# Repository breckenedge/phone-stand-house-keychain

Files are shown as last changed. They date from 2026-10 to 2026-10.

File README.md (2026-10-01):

# House Keychain Phone Stand

A 1" × 1" × 0.75" (25.4 × 25.4 × 19 mm) house keychain. The front half swings
down on a print-in-place hinge and turns into a phone stand. The lid's roof
edge overlaps the back half's roof like a shingle and snaps shut: two small ridges under
its edge click into pockets in the back half's roof.

## Files

- `house_keychain.scad`: the model. Set `part` to `closed`, `open`, `print`, `body`, or `lid`.
- `house_keychain_print.stl`: the whole keychain as one print, with the lid folded open.

- `hotel_keychain.scad`: the hotel, a 1" × 2.5" × 0.75" version (see below). It includes the house model and only changes a few values.
- `hotel_keychain_print.stl`: the hotel as one print, with the lid folded open.

## Printing

- Print `house_keychain_print.stl` as exported: body upright and lid flat, joined only by the hinge.
- No supports needed.
- PETG (tougher and more heat-resistant than PLA, which matters for a keychain). 0.4 mm nozzle, 0.12 mm layers or finer.
- Use a textured plate or glue stick: PETG can bond too well to smooth PEI.
- In the slicer preview, check that the 0.35 mm hinge gaps show up as gaps and aren't filled in.
- After printing, work the hinge back and forth a few times to free it. Then fold the lid up until it clicks.

## Using it as a stand

Fold the lid down flat. Set the phone's bottom edge on the open lid, just in
front of the hinge. The phone leans back against the roof ridge at about 15°,
and the lid's roof edge acts as a lip that stops it sliding forward. Phones up
to about 12 mm thick, case included, fit between the hinge and the lip.

The stand is tiny, so **landscape is the stable orientation**. Portrait works
with lighter phones, but it can tip backward.

## The hotel

The hotel is 2.5" (63.5 mm) tall with the same footprint, hinge and roof snap.
Its whole front wall folds down into a 2.5" base. The phone's bottom edge sits
out on that base against a rib and leans back on the roof ridge at 20°. Because
the phone stands well forward of the hotel and is held 2.5" up, portrait is
stable too.

- `phone_lean`: the lean angle (20°). It sets how far out on the base the phone sits. 0 gives the house layout.
- `lip_h`: rib height (6 mm). The rib sits just past the front of a `phone_t` phone and folds away inside the closed hotel.
- `roof_h`: eave-to-peak height (9 mm).
- `floors`, `floor_h`: rows of windows and their spacing.

## Tuning

- `pip_clr`: hinge gap, 0.35 mm for PETG. Raise to 0.4 if the hinge prints fused. Lower it (0.3 suits PLA) if it's floppy.
- `open_stop`: the middle hinge knuckle has a square foot, which makes the house's bottom flat. Opened past flat, the
  foot runs head-on into the end of the body's floor, so the lid stops at about 99° (about 105° with the hinge's play
  taken up). It can't stop at exactly 90°: the foot has to print `clr` (0.3 mm) clear of the floor.
- `hinge_r`: knuckle radius, 3 mm. A bigger hinge gives a firmer stop, but it also raises the eave, which flattens the roof.
- `snap`: how firmly the lid clicks shut (how far the lid's ridges reach into the body's roof). 0.35 mm for PETG. Use 0.3 for PLA: it gives a good click in PLA but was too soft in PETG.
  The part that flexes is mostly the lid's thin roof edge. The ridges print as horizontal ribs on it, so
  their height comes from the XY accuracy of the printer, not from the layer height.
- `overlap`, `lip_t`, `fit`: how far the lid's roof edge laps over the body's roof,
  how thick that edge is, and the gap under it. `under_t` thickens the body roof
  under the overlap. `bump_dx` sets how far the ridges sit from the peak.
- `snap_ridge`: how long each ridge is along the roof slope (4 mm by default), for a firmer
  click in PETG. Set it to 0 for round bumps.
- `phone_t`: the thickest phone, case included, that the stand fits (12 mm by default). The eave
  height is calculated from it: thicker phones mean higher walls and a flatter roof. Anything over
  about 16 mm is rejected with an error. When run, the `open` view echoes the lean angle and where the lip is.
- `roof_split`: a higher value gives a more upright phone but a smaller lip.
- `keyring_d`: keyring hole size, 3 mm by default and up to about 5 mm. The hole runs sideways through the top of the
  chimney, so the ring loops over the chimney when closed and lies flat past the end of the lid
  when it's open. The chimney gets deeper and taller to fit bigger holes, and rises above the 1"
  peak from about 3 mm up. `chim_rim` sets the material around the hole and `chim_cap` the material above it.
- `chamfer`: bevel on all the outside edges (0.8 mm) so it doesn't snag in a pocket.
- `details`: door and windows. Off by default (house and hotel).

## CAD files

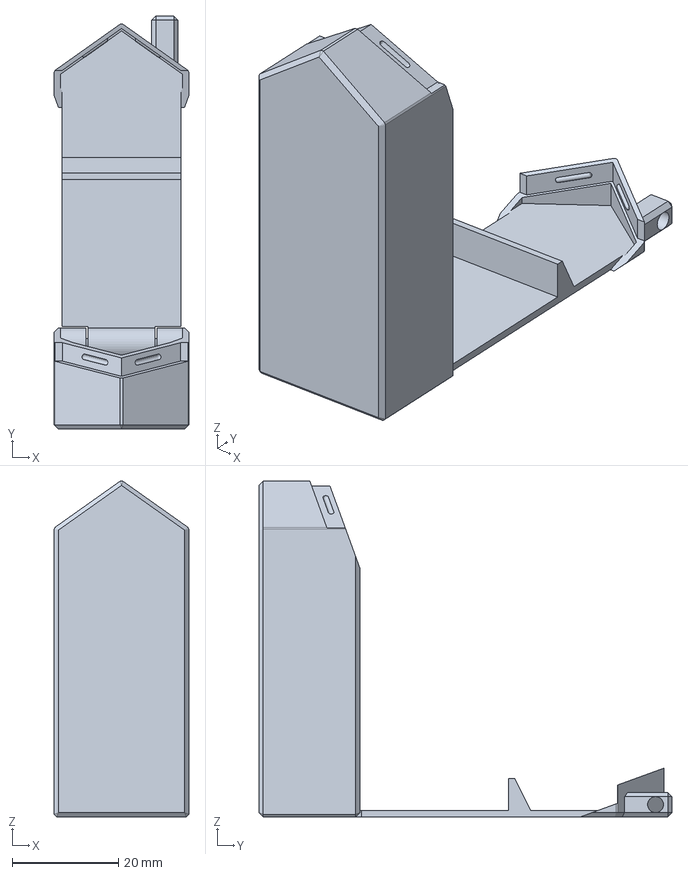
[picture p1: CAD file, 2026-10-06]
hotel_keychain_print.3mf
25.4 x 77.9 x 63.3 mm

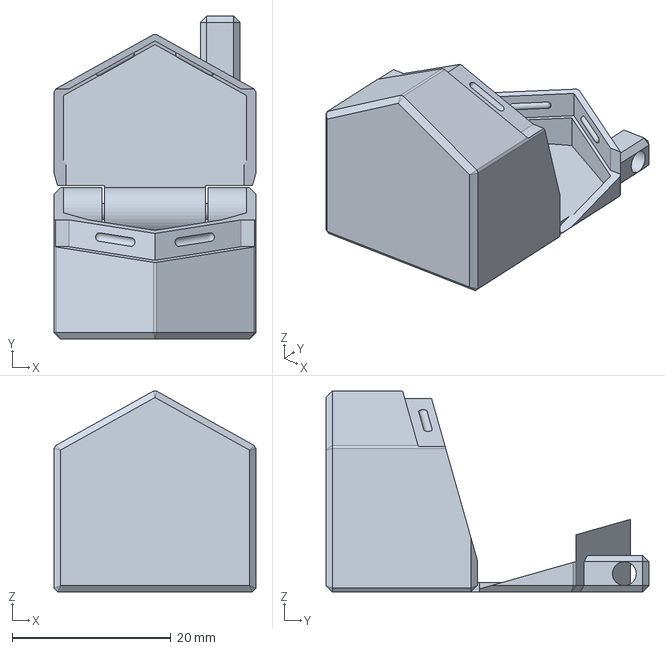
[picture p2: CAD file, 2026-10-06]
house_keychain_print.3mf
25.4 x 40.7 x 25.3 mm

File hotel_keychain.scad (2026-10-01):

// Hotel Keychain Phone Stand
// The house's tall sibling: 1" x 2.5" x 0.75". Same hinge and roof snap, but the
// whole front wall folds down into a 2.5" base. The phone's bottom edge sits out
// on that base against a rib and leans on the roof ridge, 2.5" up.
// Everything is modelled in house_keychain.scad; this file only sets the hotel's
// values (the ones here win over the house's defaults).

include <house_keychain.scad>

part = "open"; // [closed, open, print, body, lid]
H = 63.5;           // height to roof peak (2.5")
phone_lean = 20;    // degrees
floors = 4;         // window rows, if details is turned on

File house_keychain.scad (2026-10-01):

// House Keychain Phone Stand
// A 1" x 1" x 0.75" house. The front half folds down on a hinge and becomes a
// phone stand: the phone's bottom edge sits on the open lid just past the hinge,
// leans on the roof ridge, and the lid's roof edge is the lip in front.
// The body/lid seam is one slanted line along the phone's lean. On the roof, the
// lid's edge overlaps the body's roof like a shingle and snaps over two bumps.
//
// Coordinates: X = width, Y = depth (0 = back, D = front), Z = up.
// Print-in-place hinge: the lid's middle knuckle carries a pin that runs into
// blind holes in the body's end knuckles. Print the whole thing in one piece
// with the lid folded open (part = "print").

/* [View] */
part = "open"; // [closed, open, print, body, lid]
show_phone = true; // ghost phone in the "open" view

/* [Size] */
W = 25.4;           // width  (1")
H = 25.4;           // height to roof peak (1")
D = 19.05;          // depth  (0.75")
wall = 1.2;
floor_t = 1.5;
chamfer = 0.8;      // bevel on the outside edges so it doesn't snag in a pocket

/* [Hinge] */
hinge_r = 3;        // knuckle radius
pin_r = 1.0;        // print-in-place pin radius
pip_clr = 0.35;     // pin-to-hole and knuckle-to-knuckle gap; raise if it prints fused
clr = 0.3;          // moving clearance elsewhere
gap = 0.25;         // seam between body and lid
knuckle_w = 6;      // width of each outer (body) knuckle
open_stop = true;   // square foot on the lid's knuckle: it butts into the end of the body's floor just past flat

/* [Split] */
roof_split = 13.0;  // seam crosses the roof peak here (the phone leans on this edge)

/* [Roof snap] */
overlap = 3.0;      // how far the lid's roof edge laps over the body's roof
lip_t = 0.8;        // thickness of the lid's overlapping edge
fit = 0.1;          // gap under the overlapping edge
under_t = 1.2;      // body roof thickness under the overlap (thickened inward)
snap = 0.35;        // how far the lid's ridges reach into the body's roof; more = firmer
bump_dx = 5;        // ridge distance from the roof peak, on each slope
snap_ridge = 4;     // bumps stretched into ridges this long (along the slope); 0 = round bumps

/* [Phone] */
phone_t = 12;       // thickest phone (incl. case) the stand fits; sets the eave height
phone_fit = 0.1;    // extra room between that phone and the lip

/* [Hotel] */
// These turn the house into the tall hotel (see hotel_keychain.scad).
phone_lean = 0;     // phone's lean in degrees; its bottom edge then sits out on the open lid against a rib. 0 = house
roof_h = 9;         // eave-to-peak height when phone_lean is set (the house's eave comes from phone_t)
lip_h = 6;          // how far the rib stands up from the open lid
lip_w = 1.2;        // rib thickness at its top edge
floors = 1;         // rows of windows
floor_h = 12;       // spacing between the rows

/* [Features] */
details = false;    // door and windows
keyring_d = 3;      // keyring hole; the chimney grows (deeper, taller) to fit it
chim_rim = 0.8;     // chimney material beside the keyring hole and between it and the roof
chim_cap = 1.6;     // chimney material above the keyring hole

/* [Hidden] */
$fn = 40;
e = 0.01;
ay = D - hinge_r;                    // hinge axis
az = hinge_r;
floor_end = ay - hinge_r - clr;      // body floor ends here
lid_z0 = az + hinge_r + clr;         // lid front wall starts above body knuckles
lid_x0 = wall + clr;                 // lid front wall sits between body side walls
lid_x1 = W - wall - clr;
mid_x0 = knuckle_w + pip_clr;        // lid knuckle span
mid_x1 = W - knuckle_w - pip_clr;
pin_cap = 1.0;                       // closed outer end of each body knuckle
// phone's back face: bottom edge just past the hinge knuckles, leaning on the ridge
// (hotel: further out on the open lid, wherever phone_lean puts it)
rib = phone_lean > 0;
// house: far enough out that the leaning phone's back clears the knuckle by about 0.2 mm
// (worked out at the lean of a first guess; the real lean is a touch steeper, costing ~0.03 mm)
lean0 = atan((ay + hinge_r + 0.5 - roof_split) / (H - wall));
phone_by = rib ? roof_split + (H - wall) * tan(phone_lean)
               : ay + ((hinge_r - wall) * sin(lean0) + hinge_r + 0.2) / cos(lean0);
lean = atan((phone_by - roof_split) / (H - wall));
// wall height: puts the lip (the lid's roof edge at the eave, once open) just past
// the front of a phone_t phone (hotel: the rib is the lip, so the eave is free)
eave = rib ? H - roof_h : phone_by + phone_t * cos(lean) + phone_fit - ay + az - gap / 2;
assert(eave < H - 5, str("phone_t too thick: eave ", eave, " leaves too little roof"));
echo(str("eave ", eave, ", roof pitch ", atan((H - eave) / (W / 2)), " deg"));
// roof snap: ridges under the lid's edge click into pockets in the body's recessed roof
roof_k = (H - eave) / (W / 2);       // roof slope
roof_a = atan(roof_k);
recess = lip_t + fit;                // depth of the body roof's recess
bump_r = fit + snap;
assert(bump_dx - snap_ridge / 2 > 1, "snap_ridge too long: the ridges would cross the roof peak");
// hotel's rib: its phone-side face, as a height on the closed lid's front wall
rib_z = az + phone_by + phone_t * cos(lean) + phone_fit - ay;
rib_base = lip_w + lip_h / 2;        // thickness at the root
if (rib) {
    assert(rib_z + rib_base < eave, "phone_lean too steep: the rib would land on the lid's roof");
    assert(lip_h > phone_t * sin(lean) + 1, "lip_h too low to catch the phone's front corner");
    assert(lip_h < D - 2 * wall - 1, "lip_h too tall to fit inside the closed hotel");
}
function seam_y(z) = phone_by - (z - wall) * tan(lean);
function bump_pos(x) = let (z = H - abs(x - W / 2) * roof_k - recess / cos(roof_a))
    [x, seam_y(z) - overlap / 2 / cos(lean), z];

// ---------- basic shapes ----------

module pent2d() { polygon([[0, 0], [W, 0], [W, eave], [W / 2, H], [0, eave]]); }

module inner2d() {
    intersection() {
        offset(delta = -wall) pent2d();
        translate([-1, floor_t]) square([W + 2, H]);
    }
}

// extrude a profile in the XZ plane between y0 and y1
module prism(y0, y1) { translate([0, y1, 0]) rotate([90, 0, 0]) linear_extrude(y1 - y0) children(); }

// the house's outside with every edge chamfered; body and lid are clipped to it
module pent_ch(i = 0) { offset(delta = chamfer - i, chamfer = true) offset(delta = -chamfer) pent2d(); }
module envelope(i = 0) {  // i: inset
    hull() {
        prism(chamfer, D - chamfer) pent_ch(i);
        prism(i, D - i) offset(delta = -chamfer) pent_ch(i);
    }
}

// box with its top and vertical edges chamfered
module chamfered_box(s, c) {
    hull() {
        translate([c, 0, 0]) cube([s.x - 2 * c, s.y, s.z - c]);
        translate([0, c, 0]) cube([s.x, s.y - 2 * c, s.z - c]);
        translate([c, c, 0]) cube([s.x - 2 * c, s.y - 2 * c, s.z]);
    }
}

module shell() {
    difference() {
        prism(0, D) pent2d();
        prism(wall, D - wall) inner2d();
    }
}

module along_axis(x0, x1, r) {
    translate([x0, ay, az]) rotate([0, 90, 0]) cylinder(r = r, h = x1 - x0);
}

// blind holes in the body knuckles that the lid's pin turns in
module pin_holes() {
    along_axis(pin_cap, knuckle_w + e, pin_r + pip_clr);
    along_axis(W - knuckle_w - e, W - pin_cap, pin_r + pip_clr);
}

module lid_pin() { along_axis(pin_cap + pip_clr, W - pin_cap - pip_clr, pin_r); }

// everything on the phone side of its back face, grown by `off` toward the house
module phone_side(off = 0) {
    translate([-1, phone_by, wall]) rotate([lean, 0, 0]) translate([0, -off, -50]) cube([W + 2, 40, 200]);
}

// outer skin of the roof above z0, `t` thick, between planes parallel to the seam
module roof_skin(t, back, front, z0 = eave) {
    difference() {
        intersection() {
            prism(0, D) difference() { pent2d(); offset(delta = -t) pent2d(); }
            translate([-1, -1, z0]) cube([W + 2, D + 2, H]);
        }
        phone_side(-front);
        difference() { translate([-1, -1, -1]) cube([W + 2, D + 2, H + 2]); phone_side(back); }
    }
}

// ---------- body (back half + floor) ----------

// cut from the shell to leave the body: everything in front of the seam, the
// front wall, the floor in front of the hinge, and the recess under the lid's
// overlapping roof edge
module body_cuts() {
    union() {
        phone_side(0);
        translate([lid_x0 - clr, D - wall - gap, -2]) cube([lid_x1 - lid_x0 + 2 * clr, 5, H]);
        translate([wall, floor_end, -2]) cube([W - 2 * wall, D, floor_t + 2 + e]);
        roof_skin(recess, overlap + gap, 1);
    }
}
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

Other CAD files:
hotel_keychain_print.stl
house_keychain_print.stl

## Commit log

2026-09-29 House keychain phone stand with print-in-place hinge and roof latch
    [house_keychain.scad, house_keychain_print.stl]
2026-09-29 Replace roof latch with shingle-style roof snap along the seam
    [house_keychain.scad, house_keychain_print.stl]
2026-09-29 Flip house: chimney on lid, door and through-windows on back; fit ~12 mm phones
    [house_keychain.scad, house_keychain_print.stl]
2026-09-30 Parametric phone_t and keyring_d; sideways keyring hole so the open lid lies flat
    [house_keychain.scad, house_keychain_print.stl]
2026-09-30 Deeper roof snap (snap 0.3)
    [house_keychain.scad, house_keychain_print.stl]
2026-09-30 Default keyring hole 4 mm
    [house_keychain.scad, house_keychain_print.stl]
2026-09-30 Remove attic window
    [house_keychain.scad, house_keychain_print.stl]
2026-09-30 Taller door
    [house_keychain.scad, house_keychain_print.stl]
2026-09-30 Chamfer outside edges; center side windows on the closed house
    [house_keychain.scad, house_keychain_print.stl]
2026-09-30 Taller chimney: chim_cap sets material above the keyring hole
    [house_keychain.scad, house_keychain_print.stl]
2026-09-30 PETG defaults: pip_clr 0.35, README print notes
    [house_keychain.scad, house_keychain_print.stl]
2026-09-30 Default keyring hole 3 mm
    [house_keychain.scad, house_keychain_print.stl]
2026-09-30 Firmer snap for PETG (snap 0.35)
    [house_keychain.scad, house_keychain_print.stl]
2026-09-30 Snap ridges instead of round bumps for PETG (snap_ridge, 0 = bumps)
    [house_keychain.scad, house_keychain_print.stl]
2026-09-30 Hotel: 2.5" tall phone stand variant (hotel_keychain.scad)
    [hotel_keychain.scad, hotel_keychain_print.stl, house_keychain.scad]
2026-09-30 Cut the snap slots through the lid's roof edge (snap_through)
    The blind slots left a 0.35 mm skin, under one line wide, which printed
    deformed in PETG and caught the nozzle.
    [house_keychain.scad, house_keychain_print.stl]
2026-09-30 Re-export hotel STL with the through snap slots
    [hotel_keychain_print.stl]
2026-09-30 Open stop: the lid stops about 10 degrees past flat (open_stop)
    Blocks under the front of the outer hinge knuckles catch the lid's front
    wall. They print clr away from it, so the lid can't stop exactly at 90.
    [house_keychain.scad, house_keychain_print.stl]
2026-09-30 Re-export hotel STL with the open stop
    [hotel_keychain_print.stl]
2026-09-30 Door and windows off by default (details); hotel keeps them
    [hotel_keychain.scad, house_keychain.scad, house_keychain_print.stl]
2026-09-30 Swap the snap: ridges under the lid's edge, pockets in the body's roof
    The ridges now print as horizontal ribs on the lid's upright edge, so
    their height is set by XY accuracy instead of layer height. The pockets
    are blind (1.2 mm roof), so the roof has no vents. Drops snap_through.
    [hotel_keychain_print.stl, house_keychain.scad, house_keychain_print.stl]
2026-10-01 Flat-bottomed hinge stop and a bigger hinge (hinge_r 3)
    The lid's middle knuckle gets a square foot that runs head-on into the
    end of the body's floor past flat (~99 deg, ~105 with the pin's play).
    It replaces the blocks under the outer knuckles, which the lid just slid
    past. The phone's spot is now worked out from the knuckle size so the
    bigger knuckle clears it.
    [hotel_keychain_print.stl, house_keychain.scad, house_keychain_print.stl]
2026-10-01 Taper the inside roof thickening into the side walls at the eave
    It ended in a flat shelf at the eave, printed in mid-air; now its
    underside runs down at 45 degrees to the side wall's inner face.
    [hotel_keychain_print.stl, house_keychain.scad, house_keychain_print.stl]
2026-10-01 Hotel: no door or windows
    [hotel_keychain.scad, hotel_keychain_print.stl]
2026-10-06 Add 3MF print files
    [hotel_keychain_print.3mf, house_keychain_print.3mf]
